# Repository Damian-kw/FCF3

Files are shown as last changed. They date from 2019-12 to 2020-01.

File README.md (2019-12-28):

# FCF3
Flight controler for qudrocopter based on STM32F3 mcu (IN PROGRESS)
1.Controller architecture
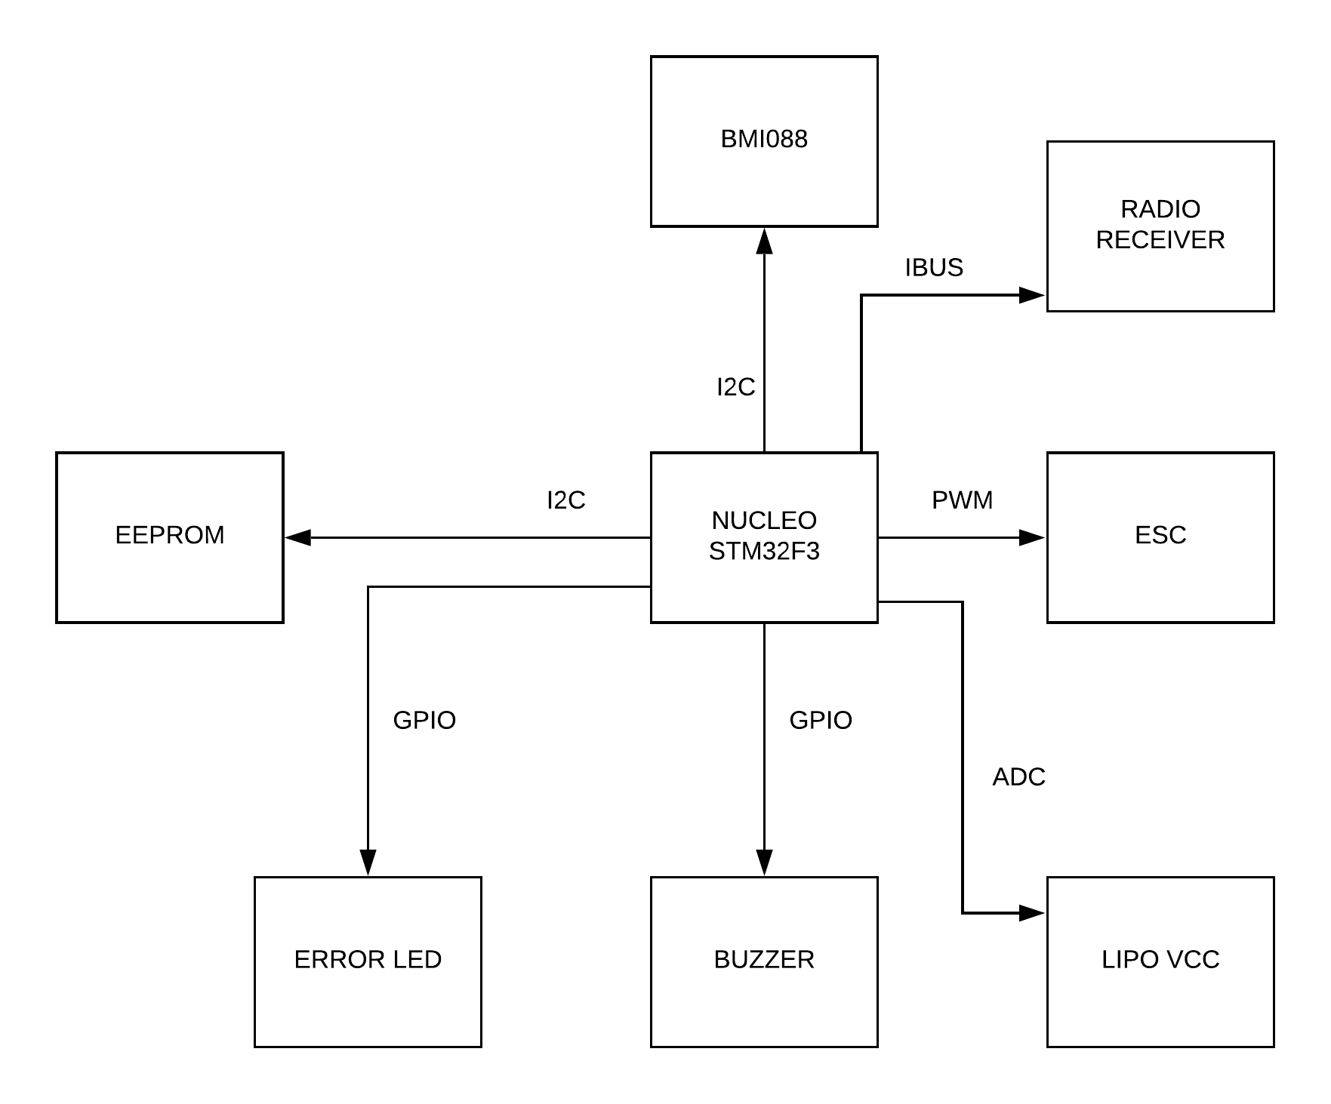
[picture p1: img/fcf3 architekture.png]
Controler_architecture

2. PCB
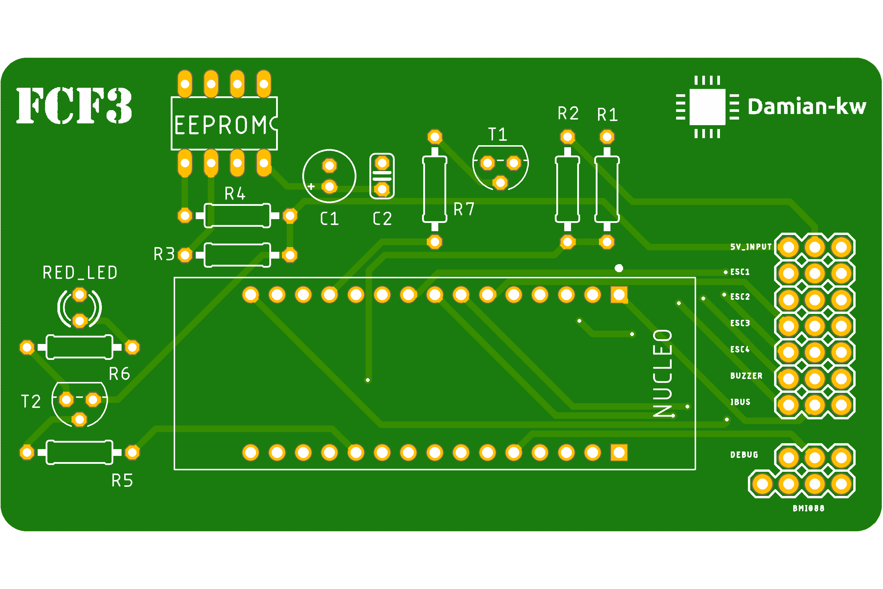
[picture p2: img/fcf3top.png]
PCB_Top

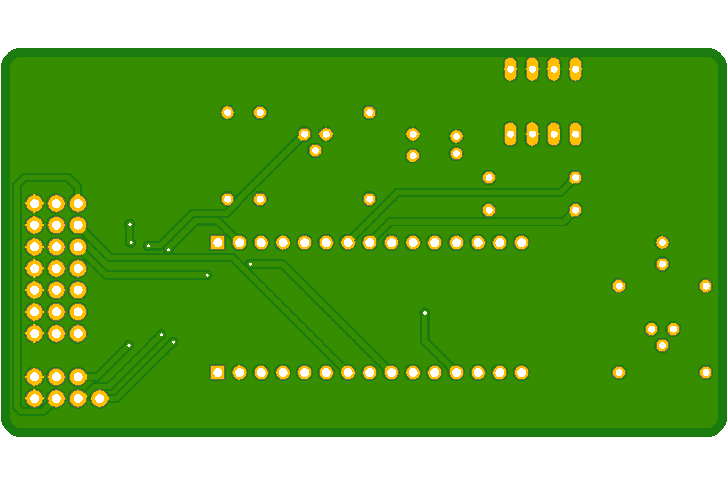
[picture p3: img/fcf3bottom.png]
PCB_Bottom


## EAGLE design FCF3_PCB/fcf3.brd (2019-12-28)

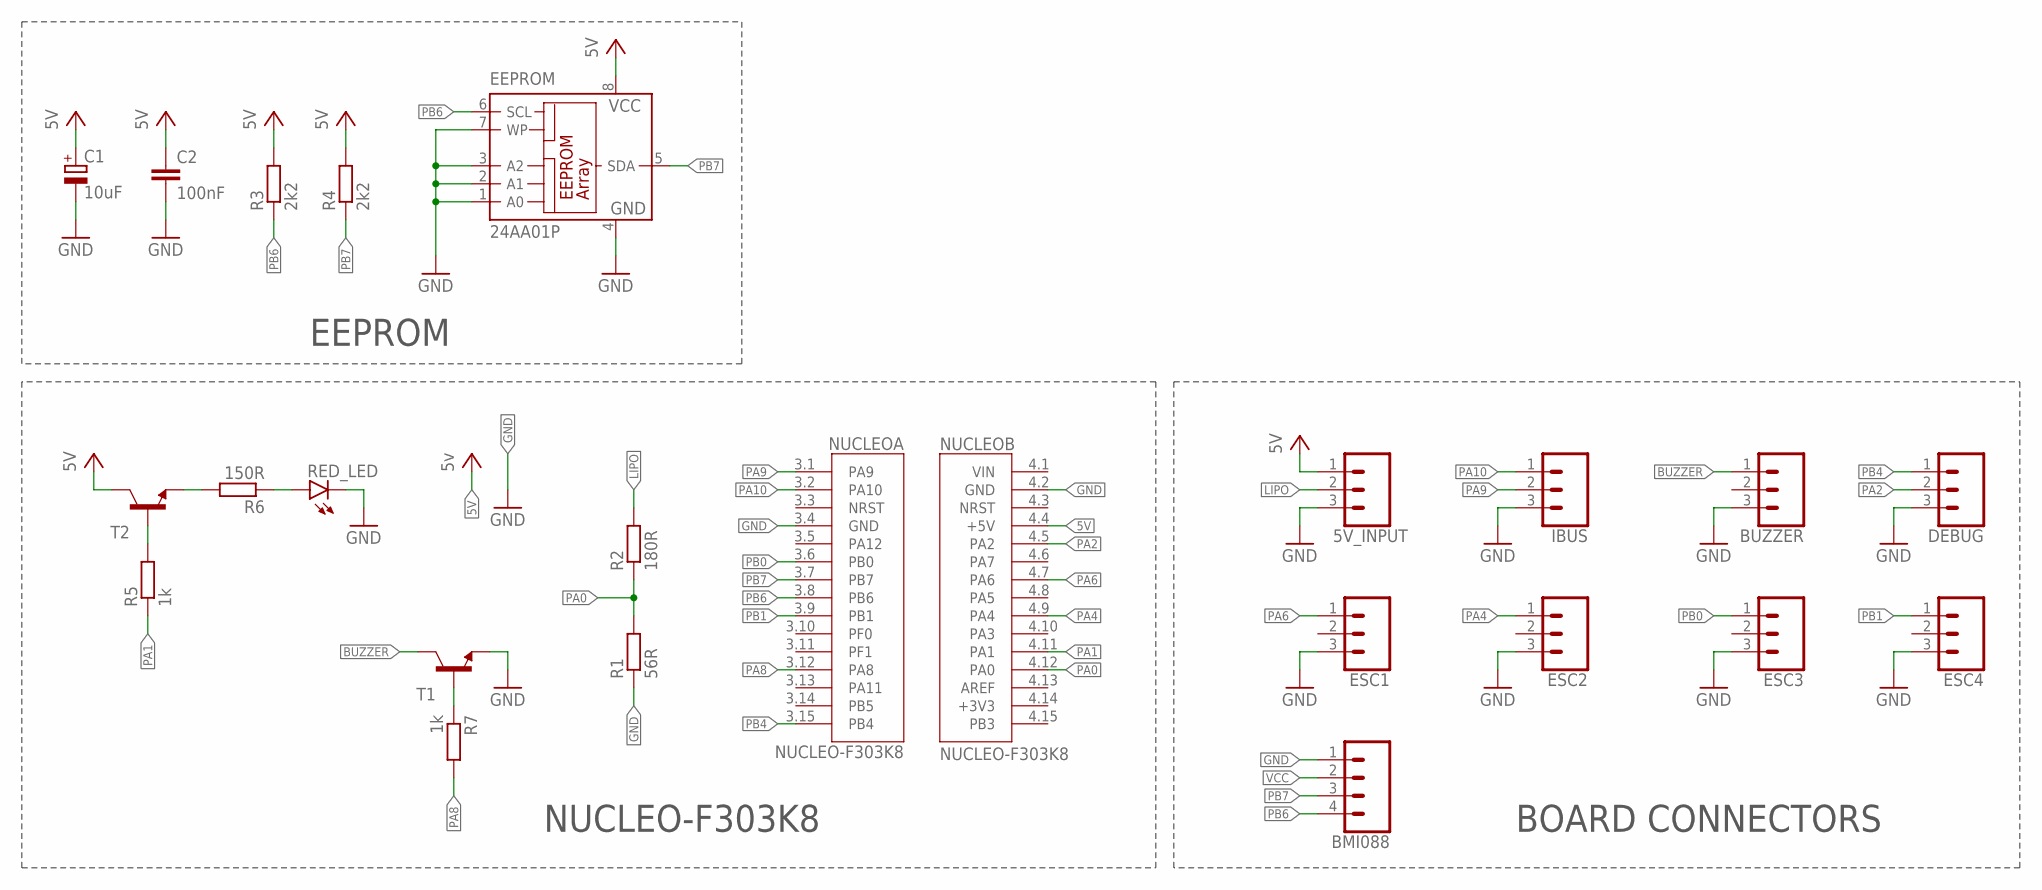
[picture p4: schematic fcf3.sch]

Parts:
5V_INPUT: CONN_03; 1X03
BMI088: CONN_04; 1X04
BUZZER: CONN_03; 1X03
C1: 10uF; E2-5
C2: 100nF; C025-024X044
DEBUG: CONN_03; 1X03
EEPROM: 24AA01P; DIL8
ESC1, ESC2, ESC3, ESC4: CONN_03; 1X03
IBUS: CONN_03; 1X03
NUCLEO: NUCLEO-F303K8; MODULE_NUCLEO-F303K8
R1: 56R; 0207/10
R2: 180R; 0207/10
R3, R4: 2k2; 0207/10
R5, R7: 1k; 0207/10
R6: 150R; 0207/10
RED_LED: LED3MM
T1, T2: -NPN-TO92; TO92

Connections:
5V: NUCLEO.4.4 (+5V)
BUZZER: BUZZER.1, T1.3 (C)
GND: 5V_INPUT.3, BMI088.1, BUZZER.3, C1.-, C2.2, DEBUG.3, EEPROM.1 (A0), EEPROM.2 (A1), EEPROM.3 (A2), EEPROM.4 (GND), EEPROM.7 (WP), ESC1.3, ESC2.3, ESC3.3, ESC4.3, IBUS.3, NUCLEO.3.4 (GND), NUCLEO.4.2 (GND), R1.1, RED_LED.K (C), T1.1 (E)
LIPO: 5V_INPUT.2, R2.2
unnamed: R5.2, T2.2 (B)
unnamed: R6.2, T2.1 (E)
unnamed: R6.1, RED_LED.A
unnamed: R7.1, T1.2 (B)
PA0: NUCLEO.4.12 (PA0), R1.2, R2.1
PA1: NUCLEO.4.11 (PA1), R5.1
PA2: DEBUG.2, NUCLEO.4.5 (PA2)
PA4: ESC2.1, NUCLEO.4.9 (PA4)
PA6: ESC1.1, NUCLEO.4.7 (PA6)
PA8: NUCLEO.3.12 (PA8), R7.2
PA9: IBUS.2, NUCLEO.3.1 (PA9)
PA10: IBUS.1, NUCLEO.3.2 (PA10)
PB0: ESC3.1, NUCLEO.3.6 (PB0)
PB1: ESC4.1, NUCLEO.3.9 (PB1)
PB4: DEBUG.1, NUCLEO.3.15 (PB4)
PB6: BMI088.4, EEPROM.6 (SCL), NUCLEO.3.8 (PB6), R3.1
PB7: BMI088.3, EEPROM.5 (SDA), NUCLEO.3.7 (PB7), R4.1
VCC: 5V_INPUT.1, BMI088.2, C1.+, C2.1, EEPROM.8 (VCC), R3.2, R4.2, T2.3 (C)

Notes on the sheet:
NUCLEO-F303K8
EEPROM
BOARD CONNECTORS

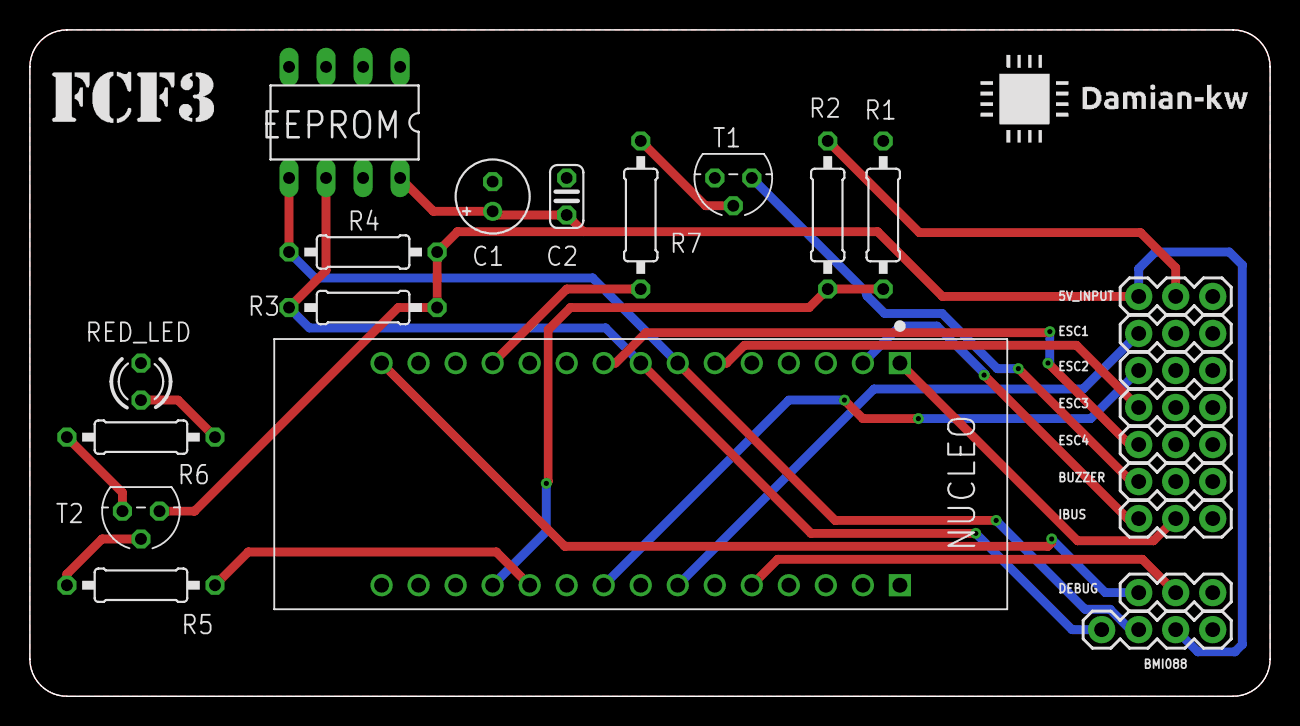
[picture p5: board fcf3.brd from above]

Board: 2 copper layers, 85.1 x 45.7 mm, 23 parts (0 on the bottom side), 21 nets.

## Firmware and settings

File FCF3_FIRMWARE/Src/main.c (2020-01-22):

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

/* Includes ------------------------------------------------------------------*/
#include "main.h"
#include "adc.h"
#include "dma.h"
#include "i2c.h"
#include "tim.h"
#include "usart.h"
#include "gpio.h"

/* USER CODE BEGIN Includes */
#include "interface_implementation.h"
#include "salloc.h"
#include "bmi088_accelerometer.h"
#include "bmi088_gyroscope.h"
#include "flight_controler.h"
/* USER CODE END Includes */

/* USER CODE BEGIN PTD */
bmi088_accelerometer accel;
bmi088_gyroscope gyro;
/* USER CODE END PTD */


void SystemClock_Config(void);
/* USER CODE BEGIN PFP */
void *malloc(size_t size);
/* USER CODE END PFP */

/**
 * @brief  The application entry point.
 * @retval int
 */
int main(void) {
	/* MCU Configuration--------------------------------------------------------*/

	/* Reset of all peripherals, Initializes the Flash interface and the Systick. */
	HAL_Init();

	/* Configure the system clock */
	SystemClock_Config();

	/* Initialize all configured peripherals */
	MX_GPIO_Init();
	MX_DMA_Init();
	MX_I2C1_Init();
	MX_USART2_UART_Init();
	MX_ADC1_Init();
	MX_TIM3_Init();
	MX_USART1_UART_Init();
	/* USER CODE BEGIN 2 */
	salloc_enable();
	gyro = bmi088_gyroscope_create(gyroscope_write_byte, gyroscope_read_byte,
				GYRO_RANGE_1000, GYRO_ODR_1000_BW_116, GYRO_NORMAL);
		if (!gyro) {
			error_handler();
		}
		uint8_t byte=2;
		data_eeprom_write_byte(0x10,byte);
		byte=0;
		byte=data_eeprom_read_byte(0x10);
		uart_dma_get_byte();
		asm("nop");

//	accel = bmi088_accelerometer_create(accelerometer_write_byte,
	//		accelerometer_read_byte, ACCEL_RANGE_3G, ACCEL_ODR_400, ACC_ACTIVE);

	//flight_controler_init();

	while (1) {

		//flight_controler_run();
	}
	/* USER CODE END 2 */

	/* Infinite loop */
	/* USER CODE BEGIN WHILE */
	while (1) {

		/* USER CODE END WHILE */

		/* USER CODE BEGIN 3 */
	}
	/* USER CODE END 3 */
}

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
/* USER CODE BEGIN 4 */
void *malloc(size_t size) {
	return salloc(size);
}
/* USER CODE END 4 */
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


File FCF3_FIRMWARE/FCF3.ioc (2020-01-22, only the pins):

Mcu.UserName=STM32F303K8Tx
PA0.GPIO_Label=lipo
PA0.Signal=ADC1_IN1
PA1.GPIO_Label=error_led
PA1.Signal=GPIO_Output
PA10.Signal=USART1_RX
PA13.GPIO_Label=SWDIO
PA13.Signal=SYS_JTMS-SWDIO
PA14.GPIO_Label=SWCLK
PA14.Signal=SYS_JTCK-SWCLK
PA2.GPIO_Label=VCP_TX
PA2.Signal=USART2_TX
PA4.Signal=S_TIM3_CH2
PA6.Signal=S_TIM3_CH1
PA8.GPIO_Label=buzzer
PA8.Signal=GPIO_Output
PA9.Signal=USART1_TX
PB0.Signal=S_TIM3_CH3
PB1.Signal=S_TIM3_CH4
PB4.GPIO_Label=VCP_RX
PB4.Signal=USART2_RX
PB6.Signal=I2C1_SCL
PB7.Signal=I2C1_SDA

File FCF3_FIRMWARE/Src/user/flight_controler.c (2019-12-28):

/*
 * flight_controler.c
 *
 *  Created on: 9 lip 2019
 *      Author: damiank
 */
#include "uart.h"
#include "esc.h"
#include "imu.h"
#include "battery_monitor.h"
#include "pid_controler.h"
#include "buzzer.h"
#include "complementary_filter.h"
#include "MedianFilter.h"
#include "float_compare.h"
#include "moving_average.h"
#include "flight_controler.h"
#include "ibus_receiver.h"
#include "bmi088_gyroscope.h"
#include "bmi088_accelerometer.h"
#include "interface_implementation.h"
#include "eeprom.h"
#include "salloc.h"
#include <stdio.h>
#include <stm32f3xx.h>
#define CHANNELS_NUMBER 6
#define MEDIAN_FILTER_ELEMENTS 7
#define CHANNEL_GAP_US 2050
typedef enum STATES_ENUM {
	FLYING = 0,
	GET_MPU_DATA = 1,
	UPDATE_IMU = 2,
	CALCULATE_PIDS = 3,
	WRITE_TO_ESC = 4,
	GET_IBUS_FRAME = 5
} STATES;
typedef enum CHANNELS_ENUM {
	THROTTLE_CHANNEL = 2,
	ROLL_CHANNEL = 0,
	PITCH_CHANNEL = 1,
	YAW_CHANNEL = 3,
	ARM_CHANNEL = 4,
	MODE_CHANNEL = 5,

} CHANNELS;
static const uint16_t FLIGHT_LOOP_FREQUENCY_HZ = 1000;
//flight controler objects
static sMedianFilter_t median_filter;
static sMedianNode_t median_buffer[MEDIAN_FILTER_ELEMENTS];
volatile static ibus_receiver radio_receiver;
static uart debug_uart;
static bmi088_gyroscope gyroscope;
static bmi088_accelerometer accelerometer;
static esc esc1;
static esc esc2;
static esc esc3;
static esc esc4;
static eeprom data_eeprom;
static battery_monitor battery;
static buzzer system_buzzer;
static pid_controler pid_controler_pitch_acro;
static pid_controler pid_controler_roll_acro;
static pid_controler pid_controler_yaw_acro;
static moving_average battery_moving_average;
//internal vars
uint32_t channels[CHANNELS_NUMBER];
volatile uint32_t fc_state;
int32_t pitch_output;
int32_t roll_output;
int32_t yaw_output;
float dt;
static uint32_t receiver_throttle;
static uint32_t receiver_arm;
static uint32_t receiver_mode;
static uint32_t receiver_pitch;
static uint32_t receiver_roll;
static uint32_t receiver_yaw;
static float accel_x;
static float accel_y;
static float accel_z;
static int32_t gyro_x;
static int32_t gyro_y;
static int32_t gyro_z;
static const int16_t ROLL_MIN_DPS = -180;
static const int16_t ROLL_MAX_DPS = 180;
static const int16_t PITCH_MIN_DPS = -180;
static const int16_t PITCH_MAX_DPS = 180;
static const int16_t YAW_MIN_DPS = -180;
static const int16_t YAW_MAX_DPS = 180;
static const int16_t PITCH_MAX_ANGLE = 30;
static const int16_t PITCH_MIN_ANGLE = -30;
static const int16_t ROLL_MAX_ANGLE = 30;
static const int16_t ROLL_MIN_ANGLE = -30;
static const int16_t ESC_MIN_ADJUST = -20;
static const int16_t ESC_MAX_ADJUST = 20;
static const float minimum_battery_voltage = 11.5;
static float accelerometer_pitch_angle;
static float accelerometer_roll_angle;
static bool is_new_flight_loop_time();
static bool is_drone_disarmed();
static bool is_new_ibus_frame();
int32_t map_int32(int32_t x, int32_t in_min, int32_t in_max, int32_t out_min,
		int32_t out_max);
static void flight_controler_set_state(uint32_t state);
static uint32_t flight_controler_get_state();
static void flight_controler_get_mpu_data();
static void flight_controler_get_ibus_frame();
static void flight_controler_write_to_esc();
static void flight_controler_update_imu();
static void flight_controler_calculate_pids();
static void flight_controler_flying();
void flight_controler_execute_get_mpu_data() {
	flight_controler_get_mpu_data();
}
void flight_controler_execute_arm() {
	flight_controler_flying();
}
void flight_controler_write_to_uart(char *msg) {
	uart_write_string(debug_uart, msg);
}
static bool is_new_flight_loop_time() {
	static uint32_t counter_us = 0;
	counter_us += get_micros();
	if (counter_us >= (1000000 / FLIGHT_LOOP_FREQUENCY_HZ)) {
		counter_us = 0;
		return true;
	}
	return false;

}
static bool is_drone_disarmed() {
	if (receiver_arm < 1200) {
		return true;
	}
	return false;
}
static bool is_new_ibus_frame() {
	return ibus_receiver_is_new_frame_avaible(radio_receiver);
}
int32_t map_int32(int32_t x, int32_t in_min, int32_t in_max, int32_t out_min,
		int32_t out_max) {
	return (x - in_min) * (out_max - out_min) / (in_max - in_min) + out_min;
}
static void flight_controler_set_state(uint32_t state) {
	fc_state = state;
}
static uint32_t flight_controler_get_state() {
	return fc_state;
}
uint32_t flight_controler_get_micros() {
	return get_micros();
}
void flight_controler_set_new_ibus_receiver_value(uint8_t value) {
	ibus_receiver_set_new_received_value(radio_receiver, value);
}
void flight_controler_init() {
	median_filter.numNodes = MEDIAN_FILTER_ELEMENTS;
	median_filter.medianBuffer = median_buffer;
	int init_result = MEDIANFILTER_Init(&median_filter);
	if (init_result == -1) {
		error_handler();
	}
	salloc_enable();
	accelerometer = bmi088_accelerometer_create(accelerometer_write_byte,
			accelerometer_read_byte, ACCEL_RANGE_3G, ACCEL_ODR_400, ACC_ACTIVE);
	if (accelerometer) {
		error_handler();
	}
	gyroscope = bmi088_gyroscope_create(gyroscope_write_byte,
			gyroscope_read_byte, GYRO_RANGE_1000, GYRO_ODR_1000_BW_116,
			GYRO_NORMAL);
	if (!gyroscope) {
		error_handler();
	}
	debug_uart = uart_ctor(100, uart2_send_byte, uart2_get_byte);
	if (!debug_uart) {
		error_handler();
	}
	data_eeprom = eeprom_ctor(data_eeprom_write_byte, data_eeprom_read_byte);
	if (!data_eeprom) {
		error_handler();
	}
	esc1 = esc_ctor(125, 250, esc1_write_pulse);
	if (!esc1) {
		error_handler();
	}
	esc2 = esc_ctor(125, 250, esc2_write_pulse);
	if (!esc2) {
		error_handler();
	}
	esc3 = esc_ctor(125, 250, esc3_write_pulse);
	if (!esc3) {
		error_handler();
	}
	esc4 = esc_ctor(125, 250, esc4_write_pulse);
	if (!esc4) {
		error_handler();
	}
	battery = battery_monitor_ctor(3, 4096, battery_adc_get_voltage);
	if (!battery) {
		error_handler();
	}
	system_buzzer = buzzer_ctor(system_buzzer_on, system_buzzer_off);
	if (!system_buzzer) {
		error_handler();
	}
	pid_controler_pitch_acro = pid_controler_ctor(0, 0, 0);
	if (!pid_controler_pitch_acro) {
		error_handler();
	}
	pid_controler_roll_acro = pid_controler_ctor(0, 0, 0);
	if (!pid_controler_roll_acro) {
		error_handler();
	}
	pid_controler_yaw_acro = pid_controler_ctor(0, 0, 0);
	if (!pid_controler_yaw_acro) {
		error_handler();
	}
	battery_moving_average = moving_average_ctor(17);
	if (!battery_moving_average) {
		error_handler();
	}

	radio_receiver = ibus_receiver_create(6);
	if (!radio_receiver) {
		error_handler();
	}
	start_pwm();
	start_adc();
	HAL_Delay(5000);
	bmi088_accelerometer_calibrate(accelerometer);
	bmi088_gyroscope_calibrate(gyroscope);
	flight_controler_set_state(FLYING);
	HAL_Delay(2000);
	uart_dma_get_byte();
}
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

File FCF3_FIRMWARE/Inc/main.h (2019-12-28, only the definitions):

#define MCO_Pin GPIO_PIN_0
#define MCO_GPIO_Port GPIOF
#define lipo_Pin GPIO_PIN_0
#define lipo_GPIO_Port GPIOA
#define error_led_Pin GPIO_PIN_1
#define error_led_GPIO_Port GPIOA
#define VCP_TX_Pin GPIO_PIN_2
#define VCP_TX_GPIO_Port GPIOA
#define buzzer_Pin GPIO_PIN_8
#define buzzer_GPIO_Port GPIOA
#define SWDIO_Pin GPIO_PIN_13
#define SWDIO_GPIO_Port GPIOA
#define SWCLK_Pin GPIO_PIN_14
#define SWCLK_GPIO_Port GPIOA
#define VCP_RX_Pin GPIO_PIN_4
#define VCP_RX_GPIO_Port GPIOB

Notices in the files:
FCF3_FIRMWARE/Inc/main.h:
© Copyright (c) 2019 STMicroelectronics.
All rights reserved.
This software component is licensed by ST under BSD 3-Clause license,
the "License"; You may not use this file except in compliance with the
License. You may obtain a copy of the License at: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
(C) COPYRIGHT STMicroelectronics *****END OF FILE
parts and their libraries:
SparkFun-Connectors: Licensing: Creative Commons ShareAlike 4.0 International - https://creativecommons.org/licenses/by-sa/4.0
